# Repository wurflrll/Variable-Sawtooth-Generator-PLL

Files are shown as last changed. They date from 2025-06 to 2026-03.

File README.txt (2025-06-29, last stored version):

For another project I needed to generate variable frequency and amplitude sawtooth waveforms. Initially what I wanted was to make a small personal function
generator and interface for an 8-ohm speaker just for fun.  In the process I was thinking about having multiple channels, and in particular what if I wanted
to generate an additional sawtooth with given phase difference but identical frequency.  This I decided was enough for it's own PCB.  There are three reference 
signals: amplitude, frequency, and phase offset.  The circuit is analog and made out of discrete components, but an ESP32 & DAC is included if the user doesn't want 
to generate reference signals externally. The phase reference works by resetting channel 2 when channel 1 is equal to the phase reference.  The tricky part
is that the frequency of the two signals are determined by their 2 RC time constants.  I wanted the slope of channel 2 to match the slope of channel 1
irrespective of component tolerances (and for example without relying on example a small tolerance shunt resistor).  This circuit taught me a lot about 
hysteresis and the whole circuit is just one op-amp feedback circuit inside of another.  An LTSpice simulation file will be added as well.

The three ref signals:

Amplitude (AMP_REF): Identically determines amplitude (eg. 3V input creates 3V amplitude of Sawtooth)

Frequency (FREQ_REF): The FREQ_ref signals actually determines the slope of the sawtooth, where 1V input = 2V/millisecond slope
So the frequency equation is simply Frequency (in kHz) = 2 * FREQ / AMP_REF

Phase Offset: The phase offset is simply 360 degrees * PHASE_REF/AMP_REF (ie. frequency)

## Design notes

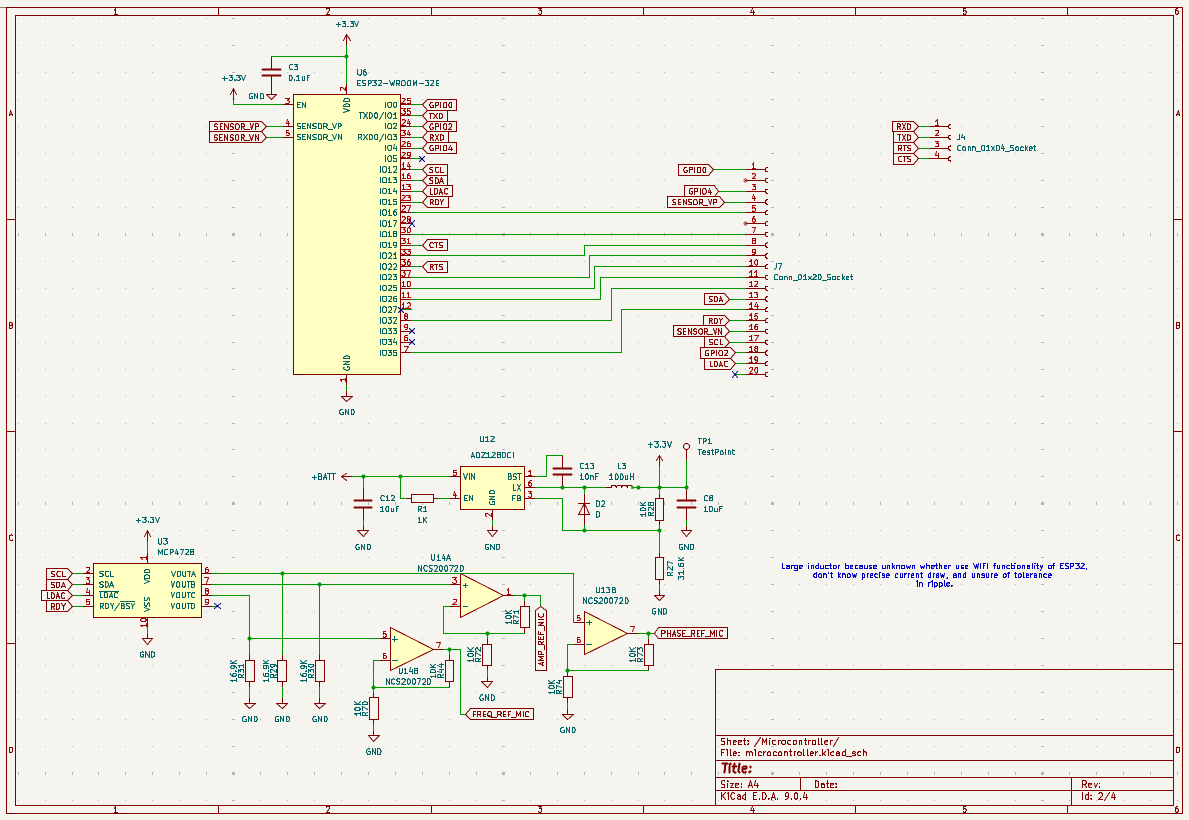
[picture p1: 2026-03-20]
Schematic_Screenshots/Microcontroller_and_Digital_Interface.png

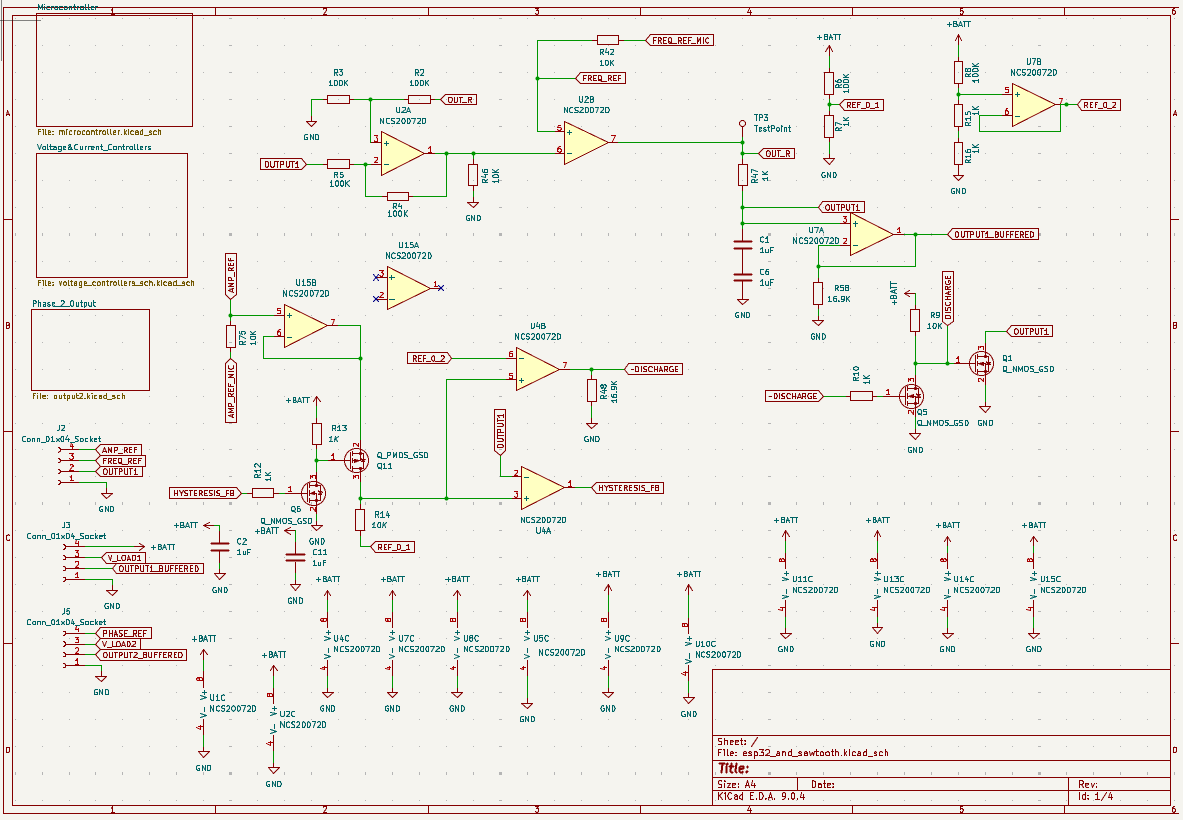
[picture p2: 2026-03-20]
Schematic_Screenshots/Channel_1_Output_Schematic.png

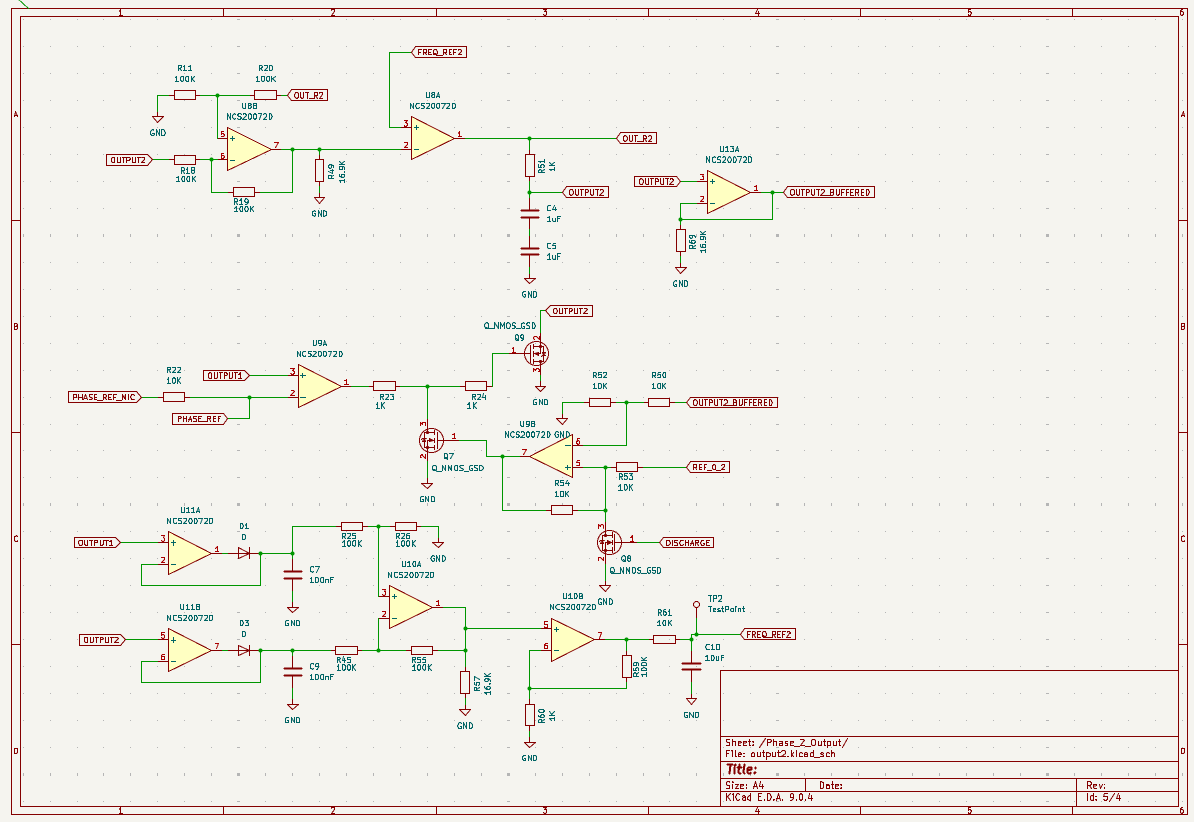
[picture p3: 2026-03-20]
Schematic_Screenshots/Output2_Control.png

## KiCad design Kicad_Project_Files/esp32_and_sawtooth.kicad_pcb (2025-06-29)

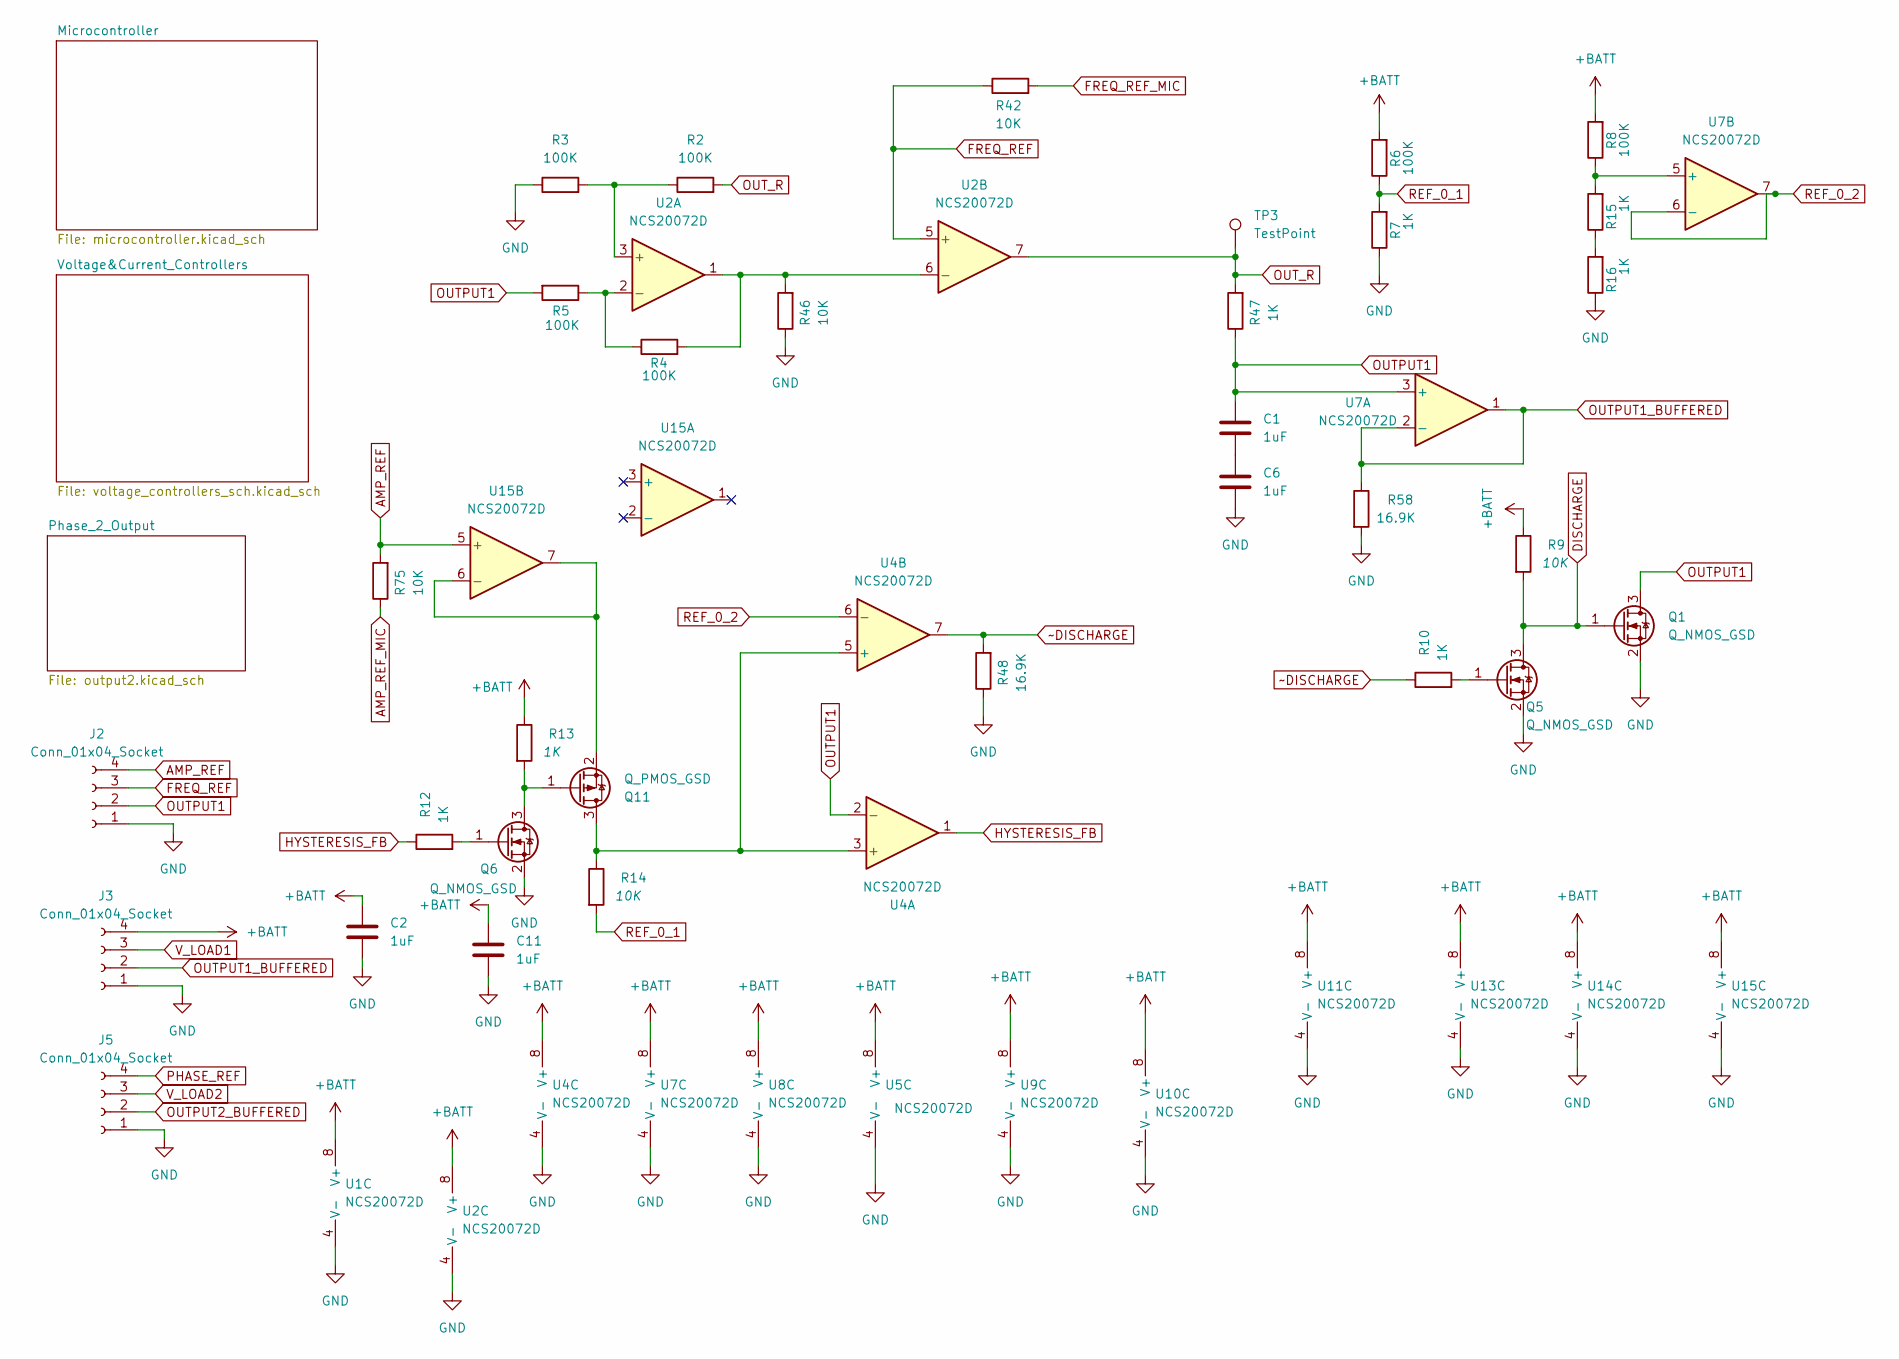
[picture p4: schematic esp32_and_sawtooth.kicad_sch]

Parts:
C1, C2, C6, C11: 1uF; C_0603_1608Metric
J2, J3, J5: Conn_01x04_Socket; PhoenixContact_MSTBVA_2,5_4-G-5,08_1x04_P5.08mm_Vertical
Q1, Q5, Q6: Q_NMOS_GSD; SOT-23
Q11: Q_PMOS_GSD; SOT-23
R2, R3, R4, R5, R6, R8: 100K; R_0603_1608Metric
R7, R10, R12, R13, R15, R16, R47: 1K; R_0603_1608Metric
R9, R14, R42, R46, R75: 10K; R_0603_1608Metric
R48, R58: 16.9K; R_0603_1608Metric
TP3: TestPoint; TestPoint_THTPad_1.0x1.0mm_Drill0.5mm
U1, U2, U4, U5, U7, U8, U9, U10, U11, U13, U14, U15: NCS20072D; SOIC-8_3.9x4.9mm_P1.27mm

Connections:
+BATT: C2.1, C11.1, J3.4, R6.2, R8.2, R9.1, R13.1, U1.8 (V+), U2.8 (V+), U4.8 (V+), U5.8 (V+), U7.8 (V+), U8.8 (V+), U9.8 (V+), U10.8 (V+), U11.8 (V+), U13.8 (V+), U14.8 (V+), U15.8 (V+); also elsewhere on the board
AMP_REF: J2.4, R75.2, U15.5 (+)
AMP_REF_MIC: R75.1; also elsewhere on the board
DISCHARGE: Q1.1 (G), Q5.3 (D), R9.2; also elsewhere on the board
FREQ_REF: J2.3, R42.1, U2.5 (+)
FREQ_REF_MIC: R42.2; also elsewhere on the board
GND: C2.2, C6.2, C11.2, J2.1, J3.1, J5.1, Q1.2 (S), Q5.2 (S), Q6.2 (S), R3.1, R7.1, R16.1, R46.1, R48.1, R58.2, U1.4 (V-), U2.4 (V-), U4.4 (V-), U5.4 (V-), U7.4 (V-), U8.4 (V-), U9.4 (V-), U10.4 (V-), U11.4 (V-), U13.4 (V-), U14.4 (V-), U15.4 (V-); also elsewhere on the board
HYSTERESIS_FB: R12.1, U4.1
unnamed: C1.2, C6.1
unnamed: Q5.1 (G), R10.2
unnamed: Q6.1 (G), R12.2
unnamed: Q11.3 (D), R14.1, U4.3 (+), U4.5 (+)
unnamed: Q6.3 (D), Q11.1 (G), R13.2
unnamed: Q11.2 (S), U15.6 (-), U15.7
unnamed: R15.1, R16.2
unnamed: R2.1, R3.2, U2.3 (+)
unnamed: R4.1, R5.1, U2.2 (-)
unnamed 53: R4.2, R46.2, U2.1, U2.6 (-); also elsewhere on the board
unnamed: R8.1, R15.2, U7.5 (+)
OUTPUT1: C1.1, J2.2, Q1.3 (D), R5.2, R47.1, U4.2 (-), U7.3 (+); also elsewhere on the board
OUTPUT1_BUFFERED: J3.2, R58.1, U7.1, U7.2 (-); also elsewhere on the board
OUTPUT2_BUFFERED: J5.2; also elsewhere on the board
OUT_R: R2.2, R47.2, TP3.1, U2.7; also elsewhere on the board
PHASE_REF: J5.4; also elsewhere on the board
REF_0_1: R6.1, R7.2, R14.2
REF_0_2: U4.6 (-), U7.6 (-), U7.7; also elsewhere on the board
V_LOAD1: J3.3; also elsewhere on the board
V_LOAD2: J5.3; also elsewhere on the board
~DISCHARGE: R10.1, R48.2, U4.7

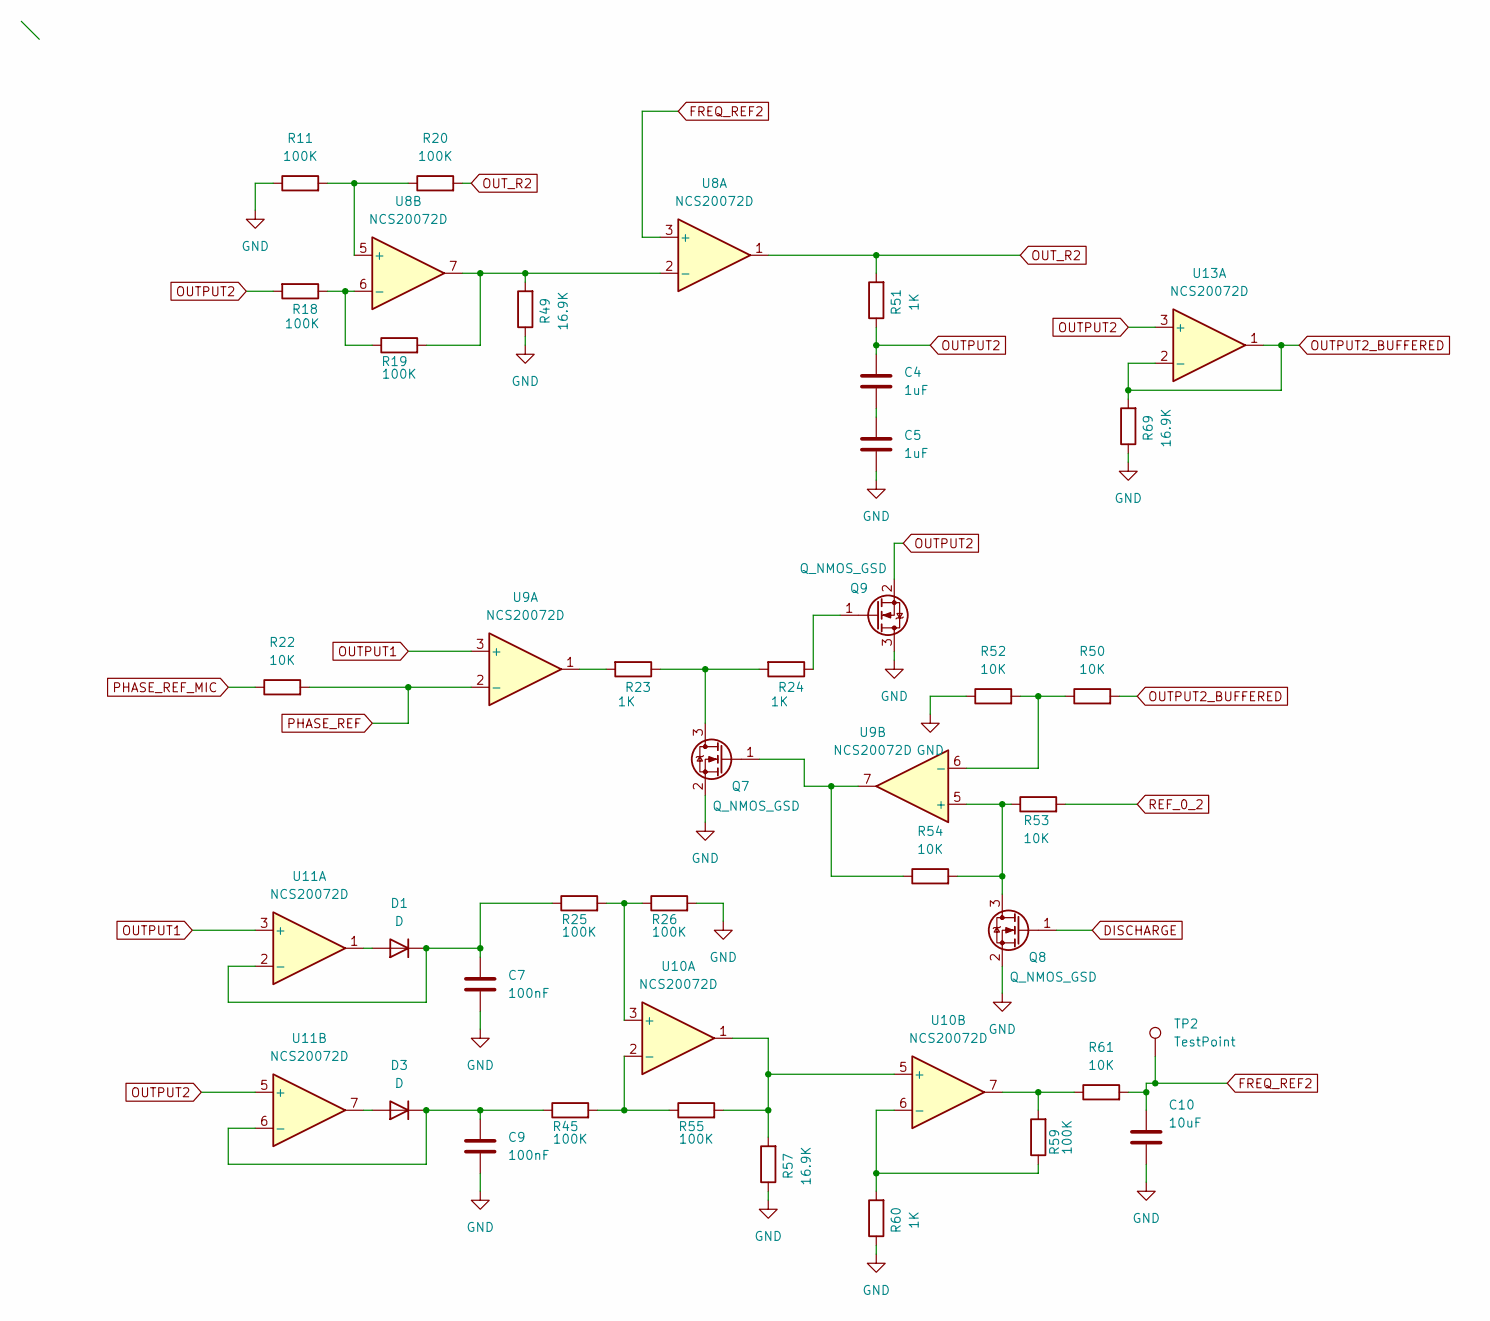
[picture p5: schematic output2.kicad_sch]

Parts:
C4, C5: 1uF; C_0603_1608Metric
C7, C9: 100nF; C_0603_1608Metric
C10: 10uF; C_0603_1608Metric
D1, D3: D; D_SMA
Q7, Q8, Q9: Q_NMOS_GSD; SOT-23
R11, R18, R19, R20, R25, R26, R45, R55, R59: 100K; R_0603_1608Metric
R22, R50, R52, R53, R54, R61: 10K; R_0603_1608Metric
R23, R24, R51, R60: 1K; R_0603_1608Metric
R49, R57, R69: 16.9K; R_0603_1608Metric
TP2: TestPoint; TestPoint_THTPad_1.0x1.0mm_Drill0.5mm
U8, U9, U10, U11, U13: NCS20072D; SOIC-8_3.9x4.9mm_P1.27mm

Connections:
DISCHARGE: Q8.1 (G); also elsewhere on the board
FREQ_REF2: C10.2, R61.2, TP2.1, U8.3 (+)
GND: C5.2, C7.2, C9.2, C10.1, Q7.2 (S), Q8.2 (S), Q9.3 (D), R11.1, R26.2, R49.1, R52.1, R57.1, R60.1, R69.1; also elsewhere on the board
unnamed: C4.2, C5.1
unnamed: D1.2 (A), U11.1
unnamed: C7.1, D1.1 (K), R25.1, U11.2 (-)
unnamed: D3.2 (A), U11.7
unnamed: C9.1, D3.1 (K), R45.1, U11.6 (-)
unnamed: Q7.3 (D), R23.1, R24.2
unnamed: Q7.1 (G), R54.1, U9.7
unnamed: Q8.3 (D), R53.1, R54.2, U9.5 (+)
unnamed: Q9.1 (G), R24.1
unnamed: R23.2, U9.1
unnamed: R59.2, R61.1, U10.7
unnamed: R19.2, R49.2, U8.2 (-), U8.7
unnamed: R11.2, R20.1, U8.5 (+)
unnamed: R18.1, R19.1, U8.6 (-)
unnamed 62: R50.1, R52.2, U9.6 (-); also elsewhere on the board
unnamed: R25.2, R26.1, U10.3 (+)
unnamed: R45.2, R55.1, U10.2 (-)
unnamed: R55.2, R57.2, U10.1, U10.5 (+)
unnamed: R59.1, R60.2, U10.6 (-)
OUTPUT1: U9.3 (+), U11.3 (+); also elsewhere on the board
OUTPUT2: C4.1, Q9.2 (S), R18.2, R51.1, U11.5 (+), U13.3 (+)
OUTPUT2_BUFFERED: R50.2, R69.2, U13.1, U13.2 (-); also elsewhere on the board
OUT_R2: R20.2, R51.2, U8.1; also elsewhere on the board
PHASE_REF: R22.2, U9.2 (-); also elsewhere on the board
PHASE_REF_MIC: R22.1; also elsewhere on the board
REF_0_2: R53.2; also elsewhere on the board

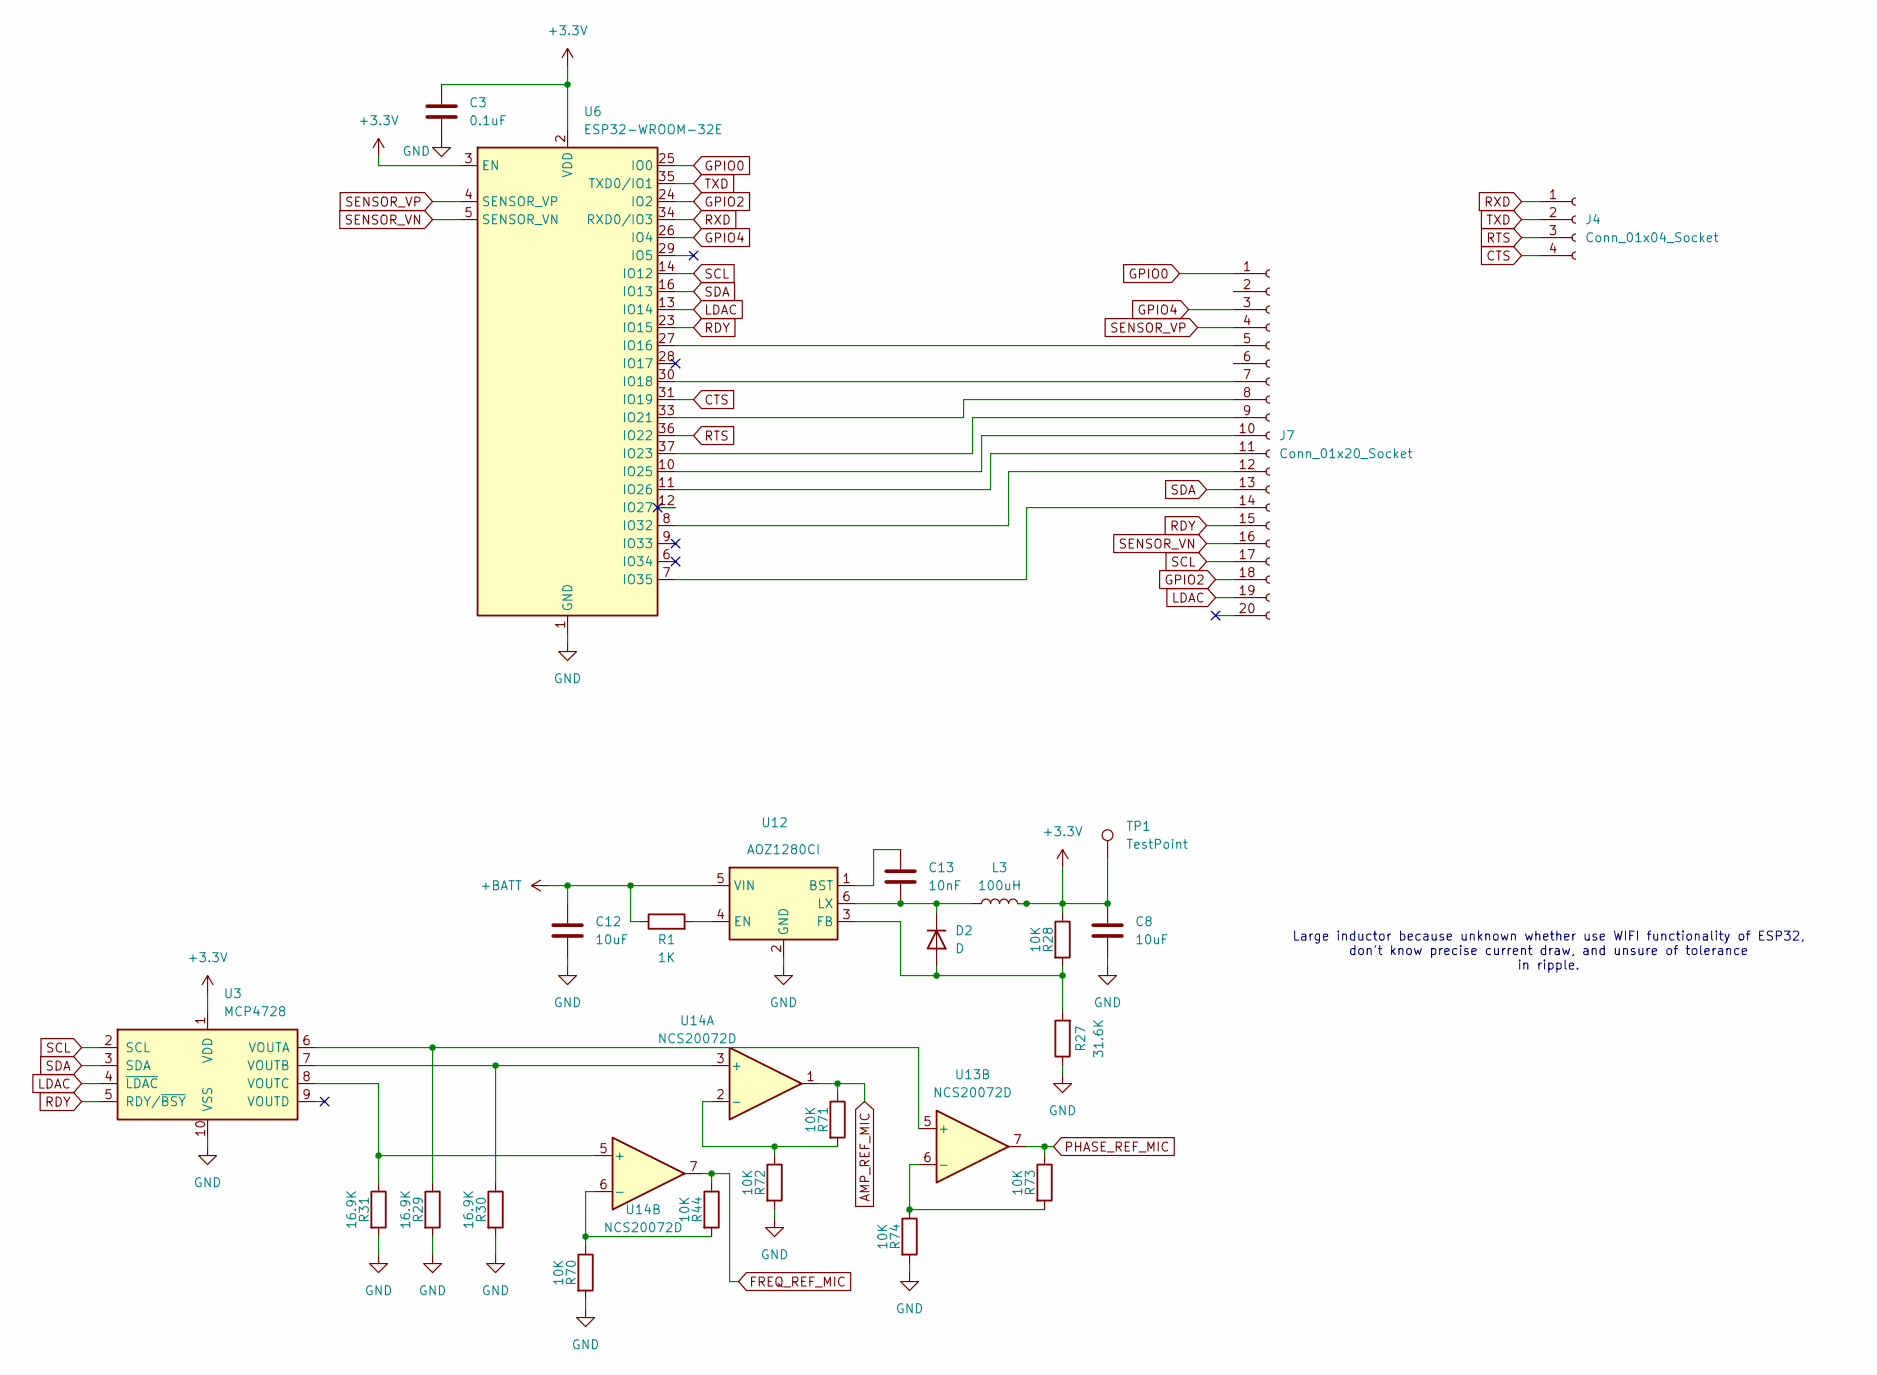
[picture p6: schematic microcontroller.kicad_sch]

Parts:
C3: 0.1uF; C_0603_1608Metric
C8, C12: 10uF; C_0603_1608Metric
C13: 10nF; C_0603_1608Metric
D2: D; D_SMA
J4: Conn_01x04_Socket; PhoenixContact_MSTBVA_2,5_4-G-5,08_1x04_P5.08mm_Vertical
J7: Conn_01x20_Socket; PinHeader_2x10_P2.54mm_Vertical
L3: 100uH; L_Radial_D8.7mm_P5.00mm_Fastron_07HCP
R1: 1K; R_0603_1608Metric
R27: 31.6K; R_0603_1608Metric
R28, R44, R70, R71, R72, R73, R74: 10K; R_0603_1608Metric
R29, R30, R31: 16.9K; R_0603_1608Metric
TP1: TestPoint; TestPoint_THTPad_1.0x1.0mm_Drill0.5mm
U3: MCP4728; MSOP-10_3x3mm_P0.5mm
U6: ESP32-WROOM-32E; ESP32-WROOM-32D
U12: AOZ1280CI; SOT-23-6
U13, U14: NCS20072D; SOIC-8_3.9x4.9mm_P1.27mm

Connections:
+3.3V: C3.1, C8.2, L3.2, R28.1, TP1.1, U3.1 (VDD), U6.2 (VDD), U6.3 (EN); also elsewhere on the board
+BATT: C12.1, R1.1, U12.5 (VIN); also elsewhere on the board
AMP_REF_MIC: R71.1, U14.1; also elsewhere on the board
CTS: J4.4, U6.31 (IO19)
FREQ_REF_MIC: R44.1, U14.7; also elsewhere on the board
GND: C3.2, C8.1, C12.2, R27.1, R29.2, R30.2, R31.2, R70.2, R72.2, R74.2, U3.10 (VSS), U6.1 (GND), U6.15 (GND), U6.38 (GND), U6.39 (GND), U12.2 (GND); also elsewhere on the board
GPIO0: J7.1, U6.25 (IO0)
GPIO2: J7.18, U6.24 (IO2)
GPIO4: J7.3, U6.26 (IO4)
LDAC: J7.19, U3.4 (~LDAC), U6.13 (IO14)
unnamed: D2.2 (A), R27.2, R28.2, U12.3 (FB)
unnamed: C13.1, D2.1 (K), L3.1, U12.6 (LX)
unnamed: J7.5, U6.27 (IO16)
unnamed: J7.7, U6.30 (IO18)
unnamed: J7.8, U6.33 (IO21)
unnamed: J7.9, U6.37 (IO23)
unnamed: J7.10, U6.10 (IO25)
unnamed: J7.11, U6.11 (IO26)
unnamed: J7.12, U6.8 (IO32)
unnamed: J7.14, U6.7 (IO35)
unnamed: C13.2, U12.1 (BST)
unnamed: R1.2, U12.4 (EN)
unnamed: R29.1, U3.6 (VOUTA), U13.5 (+)
unnamed: R73.2, R74.1, U13.6 (-)
unnamed: R30.1, U3.7 (VOUTB), U14.3 (+)
unnamed: R71.2, R72.1, U14.2 (-)
unnamed: R31.1, U3.8 (VOUTC), U14.5 (+)
unnamed: R44.2, R70.1, U14.6 (-)
PHASE_REF_MIC: R73.1, U13.7; also elsewhere on the board
RDY: J7.15, U3.5 (RDY/~BSY), U6.23 (IO15)
RTS: J4.3, U6.36 (IO22)
RXD: J4.1, U6.34 (RXD0/IO3)
SCL: J7.17, U3.2 (SCL), U6.14 (IO12)
SDA: J7.13, U3.3 (SDA), U6.16 (IO13)
SENSOR_VN: J7.16, U6.5 (SENSOR_VN)
SENSOR_VP: J7.4, U6.4 (SENSOR_VP)
TXD: J4.2, U6.35 (TXD0/IO1)

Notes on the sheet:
Large inductor because unknown whether use WIFI functionality of ESP32, don't know precise current draw, and unsure of tolerance in ripple.

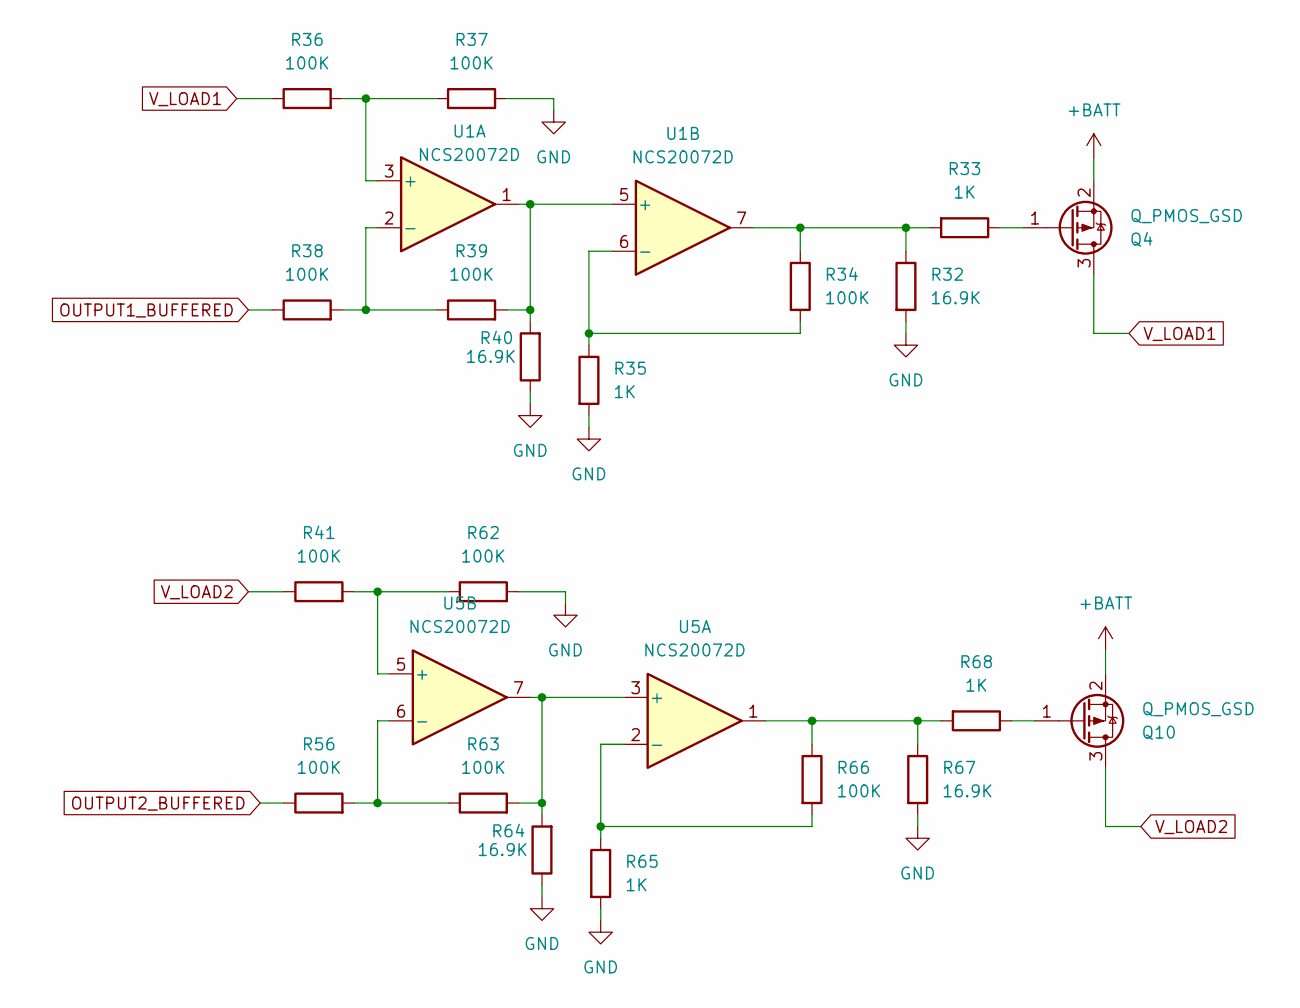
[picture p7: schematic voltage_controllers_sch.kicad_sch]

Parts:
Q4, Q10: Q_PMOS_GSD; SOT-23
R32, R40, R64, R67: 16.9K; R_0603_1608Metric
R33, R35, R65, R68: 1K; R_0603_1608Metric
R34, R36, R37, R38, R39, R41, R56, R62, R63, R66: 100K; R_0603_1608Metric
U1, U5: NCS20072D; SOIC-8_3.9x4.9mm_P1.27mm

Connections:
+BATT: Q4.2 (S), Q10.2 (S); also elsewhere on the board
GND: R32.2, R35.2, R37.2, R40.1, R62.2, R64.1, R65.2, R67.2; also elsewhere on the board
unnamed: Q4.1 (G), R33.1
unnamed: Q10.1 (G), R68.1
unnamed: R32.1, R33.2, R34.1, U1.7
unnamed: R66.1, R67.1, R68.2, U5.1
unnamed: R36.2, R37.1, U1.3 (+)
unnamed: R38.2, R39.1, U1.2 (-)
unnamed: R39.2, R40.2, U1.1, U1.5 (+)
unnamed: R34.2, R35.1, U1.6 (-)
unnamed: R63.2, R64.2, U5.3 (+), U5.7
unnamed: R65.1, R66.2, U5.2 (-)
unnamed: R41.2, R62.1, U5.5 (+)
unnamed: R56.2, R63.1, U5.6 (-)
OUTPUT1_BUFFERED: R38.1; also elsewhere on the board
OUTPUT2_BUFFERED: R56.1; also elsewhere on the board
V_LOAD1: Q4.3 (D), R36.1; also elsewhere on the board
V_LOAD2: Q10.3 (D), R41.1; also elsewhere on the board

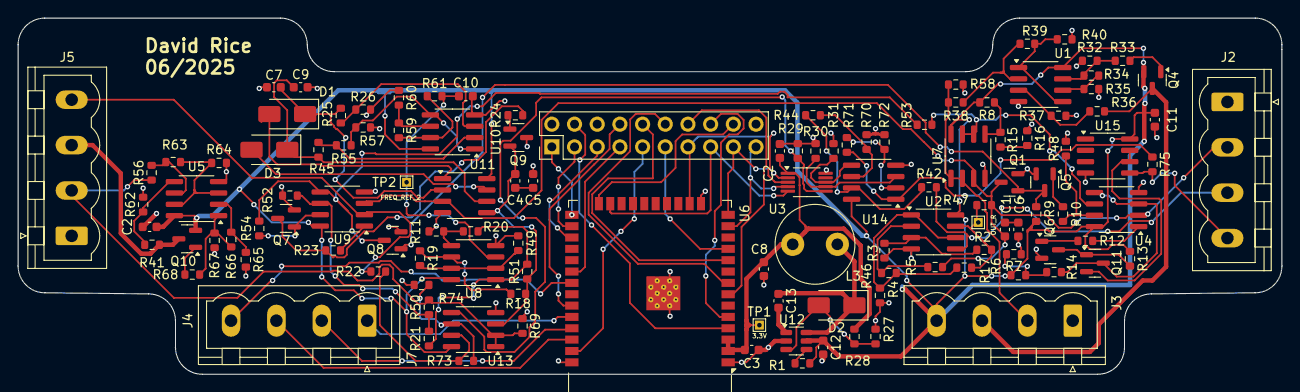
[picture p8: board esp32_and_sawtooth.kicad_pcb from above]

Board: 2 copper layers, 141.5 x 39.9 mm, 124 parts (0 on the bottom side), 96 nets.

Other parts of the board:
C2#2: 100nF; C_0603_1608Metric
R17, R21: 100K; R_0603_1608Metric

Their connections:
+3.3V: C2#2.1; also elsewhere on the board
GND: C2#2.2; also elsewhere on the board
unnamed 53: R17.1; also elsewhere on the board
unnamed 62: R21.1; also elsewhere on the board
OUT_R: R17.2; also elsewhere on the board
OUT_R2: R21.2; also elsewhere on the board

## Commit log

2025-06-29 Add files via upload
    Adding Original KiCad Files
    [esp32_and_sawtooth.kicad_pcb, esp32_and_sawtooth.kicad_sch, microcontroller.kicad_sch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]
2026-03-20 Update Discriptions / Add Screenshots of Schematics
    [esp32_and_sawtooth.kicad_sch]
2026-03-20 Fix Project Folder
    [esp32_and_sawtooth.kicad_pcb, esp32_and_sawtooth.kicad_sch, microcontroller.kicad_sch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]
